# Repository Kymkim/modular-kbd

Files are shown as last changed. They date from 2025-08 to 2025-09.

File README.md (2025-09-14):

# MSKBD - Modularly Simple KeyBoarD

> [!WARNING]  
> This is under development. If you want the latest developments check out the `dev` branch.

A customizable modular keyboard system where each key cluster is its own module, connected through a grid-like commnication. The goal is to create a flexible keyboard that can scale, reconfigure layouts, and support hot-swapping modules.

## Features
- 🧩 **Modular design** — attach modules in any direction
- 🎛️ **Configurable firmware** — master + module code, easily updated
- ⚡ **Hotplug detection** — modules can be discovered dynamically

# Numpad Module

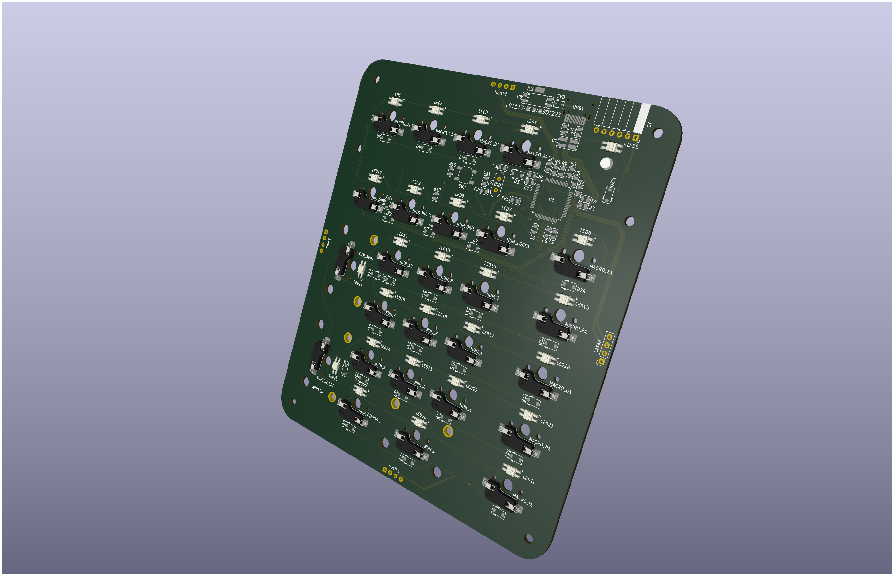
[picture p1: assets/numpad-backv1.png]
Numpad Rear


## Repo Structure
```
├─firmware/ - Embedded code for the core system
├─hardware/ - Schematics and PCB layouts
├─software/ - Host tools (keymap editor, etc.) (not yet implemented - soon hopefully!)
├─docs/ - Design notes, communication protocol, build guides
└─assets/ - Renders, diagrams, and media
```

## Branch Structure
```
main              # Stable, production-ready code (only tested & reviewed changes go here)
│
├─ dev            # Integration branch for features; "staging" area before merging to main
│  ├─ software-xxxxxx     # New features, experiments, improvements, or PCB uploads    
|  ├─ firmware-xxxxxx     # Please indicate in the branch the wether if its software
│  └─ hardware-xxxxxx     # firmware, or hardware
│
├─ hotfix/        # Quick fixes for urgent bugs in main
│   └─ hotfix/usb-detection
│
└─ docs/          # Documentation updates
    └─ docs/protocol-update
```

## Contributors
<a href="https://github.com/Kymkim/modular-kbd/graphs/contributors">
  
</a>

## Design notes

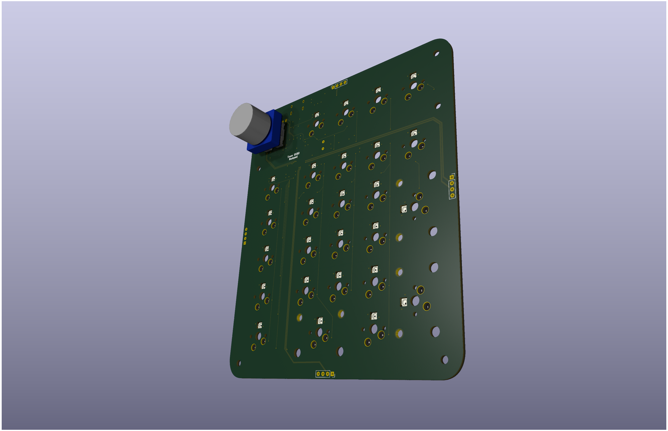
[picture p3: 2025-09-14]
assets/numpad-frontv1.png

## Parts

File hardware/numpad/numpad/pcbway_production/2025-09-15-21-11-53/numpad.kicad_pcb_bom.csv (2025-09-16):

Designator | Quantity | Value | Footprint | Package | MPN | DNP | Mount_Type | Description | Specifications | Manufacturer
C1, C2 | 2 | 20pF | C_0805_2012Metric |  |  |  | smt | SMD 0805 MLCC capacitor, Alternate KiCad Library
C10, C7 | 2 | 1uF | C_0805_2012Metric |  |  |  | smt | SMD 0805 MLCC capacitor, Alternate KiCad Library
C11 | 1 | 0.1uF | C_0805_2012Metric |  |  |  | smt | SMD 0805 MLCC capacitor, Alternate KiCad Library
C3, C4, C5, C6 | 4 | 100nF | C_0805_2012Metric |  |  |  | smt | SMD 0805 MLCC capacitor, Alternate KiCad Library
C8 | 1 | 10uF | C_0805_2012Metric |  |  |  | smt | SMD 0805 MLCC capacitor, Alternate KiCad Library
C9 | 1 | 4.7uF | C_0805_2012Metric |  |  |  | smt | SMD 0805 MLCC capacitor, Alternate KiCad Library
D1 | 1 | PRTR5V0U2X | SOT-143_Handsoldering |  |  |  | smt | SOT-143 TVS Diode Array, 2 protected lines, 5.5V, Alternate KiCAD Library
D10, D11, D12, D13, D14, D15, D16, D17, D18, D19, D20, D21, D22, D23, D24, D25, D26, D27, D28, D29, D3, D4, D5, D6, D7, D8, D9 | 27 | 1N4148W | D_SOD-123 |  |  |  | smt | SOD-123 Diode, Small Signal, Fast Switching, 75V, 150mA, 4ns, Alternate KiCad Library
D2 | 1 | BAT60JFILM | D_SOD-323 |  |  |  | smt | Diode
EAST, NORTH, SOUTH, WEST | 4 | Conn_01x04 | PinSocket_1x04_P2.54mm_Vertical |  | 1-0401FBV0T |  | tht | HEADER 1x4 MALE PINS 0.100” 180deg | HEADER 1x4 MALE PINS 0.100” 180deg | TAD
FB1 | 1 | Ferrite_Bead | Fuse_0805_2012Metric_Pad1.15x1.40mm_BigPads |  |  |  | smt | Ferrite bead, Alternate KiCAD Library
IC1 | 1 | LD1117 | SOT223 |  | LD1117S33CTR |  | tht | 3.3V Voltage Regulator, SOT-223-3, Imax=0.8A, VinMax=15V, Vdrop=1V |  | STMicroelectronics
J1 | 1 | Conn_01x06 | PinSocket_1x06_P2.54mm_Horizontal |  | 1-0601FBV0T |  | tht | HEADER 1x6 MALE PINS 0.100” 180deg | HEADER 1x6 MALE PINS 0.100” 180deg | TAD
LED1, LED10, LED11, LED12, LED13, LED14, LED15, LED16, LED17, LED18, LED19, LED2, LED20, LED21, LED22, LED23, LED24, LED25, LED26, LED27, LED3, LED4, LED5, LED6, LED7, LED8, LED9 | 27 | MX_SK6812MINI-E | LED_MX_6028R |  |  |  | smt | Reverse mount adressable LED (WS2812 protocol)
MACRO_A1, MACRO_B1, MACRO_C1, MACRO_D1, MACRO_E1, MACRO_F1, MACRO_G1, MACRO_H1, MACRO_I1, NUM_0, NUM_1, NUM_10, NUM_2, NUM_3, NUM_4, NUM_5, NUM_6, NUM_7, NUM_8, NUM_ADD1, NUM_DIV1, NUM_ENTER1, NUM_LOCK1, NUM_MULT1, NUM_PERIOD1, NUM_SUB1 | 26 | MX_SW_HS | SW_MX_HS_CPG151101S11_1u |  |  |  | smt | Push button switch, normally open, two pins, 45° tilted, Kailh CPG151101S11 for Cherry MX style switches
R1, R2 | 2 | 5.1k | R_0805_2012Metric |  |  |  | smt | SMD 0805 Chip Resistor, European Symbol, Alternate KiCad Library
R10 | 1 | DNP | R_0805_2012Metric |  |  | Yes | smt | SMD 0805 Chip Resistor, European Symbol, Alternate KiCad Library
R13 | 1 | DNP | R_0805_2012Metric |  |  | Yes | smt | SMD 0805 Chip Resistor, European Symbol, Alternate KiCad Library
R3, R4, R6, R7, R8, R9 | 6 | 22 | R_0805_2012Metric |  |  |  | smt | SMD 0805 Chip Resistor, European Symbol, Alternate KiCad Library
R5 | 1 | 10k | R_0805_2012Metric |  |  |  | smt | SMD 0805 Chip Resistor, European Symbol, Alternate KiCad Library
S1, S2, S3 | 3 | MX_stab | STAB_MX_P_2u |  |  |  | tht | Cherry MX-style stabilizer
SW2 | 1 | Push_Button | SW_SPST_SKQG_WithStem |  |  |  | smt | Common 6mmx6mm Push Button
U1 | 1 | ~ | LQFP64-10x10mm |  |  |  | smt
USB1 | 1 | HRO-TYPE-C-31-M-12 | HRO-TYPE-C-31-M-12-HandSoldering |  |  |  | smt
Y1 | 1 | 8MHz | Crystal_HC52-U_Vertical |  |  |  | tht | 8Mz Crystal

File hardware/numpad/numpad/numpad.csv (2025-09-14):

2"Reference" | Qty | Value | DNP | Exclude from BOM | Exclude from Board | Footprint | Datasheet
C1,C2 | 2 | 20pF |  |  |  | PCM_Capacitor_SMD_AKL:C_0805_2012Metric | ~
C3,C4,C5,C6 | 4 | 100nF |  |  |  | PCM_Capacitor_SMD_AKL:C_0805_2012Metric | ~
C7,C10 | 2 | 1uF |  |  |  | PCM_Capacitor_SMD_AKL:C_0805_2012Metric | ~
C8 | 1 | 10uF |  |  |  | PCM_Capacitor_SMD_AKL:C_0805_2012Metric | ~
C9 | 1 | 4.7uF |  |  |  | PCM_Capacitor_SMD_AKL:C_0805_2012Metric | ~
C11 | 1 | 0.1uF |  |  |  | PCM_Capacitor_SMD_AKL:C_0805_2012Metric | ~
D1 | 1 | PRTR5V0U2X |  |  |  | PCM_Package_TO_SOT_SMD_AKL:SOT-143_Handsoldering | https://www.tme.eu/Document/4eac14af69261014af6cc93b35742953/PRTR5V0U2X-DTE.pdf
D2 | 1 | BAT60JFILM |  |  |  | PCM_Diode_SMD_AKL:D_SOD-323
D3,D4,D5,D6,D7,D8,D9,D10,D11,D12,D13,D14,D15,D16,D17,D18,D19,D20,D21,D22,D23,D24,D25,D26,D27,D28,D29 | 27 | 1N4148W |  |  |  | PCM_Diode_SMD_AKL:D_SOD-123 | https://datasheet.octopart.com/1N4148W-HE3-18-Vishay-datasheet-17291302.pdf
East1,North1,South1,West1 | 4 | Conn_01x04 |  |  |  | Connector_PinSocket_2.54mm:PinSocket_1x04_P2.54mm_Vertical
FB1 | 1 | Ferrite_Bead |  |  |  | PCM_Fuse_AKL:Fuse_0805_2012Metric_Pad1.15x1.40mm_BigPads | ~
IC1 | 1 | LD1117-3.3V-SOT223 |  |  |  | PCM_4ms_Package_SOT:SOT223 | https://www.mouser.com/datasheet/2/389/cd00000544-1795431.pdf
J1 | 1 | Conn_01x06 |  |  |  | Connector_PinSocket_2.54mm:PinSocket_1x06_P2.54mm_Horizontal
LED1,LED2,LED3,LED4,LED5,LED6,LED7,LED8,LED9,LED10,LED11,LED12,LED13,LED14,LED15,LED16,LED17,LED18,LED19,LED20,LED21,LED22,LED23,LED24,LED25,LED26,LED27 | 27 | MX_SK6812MINI-E |  |  |  | PCM_marbastlib-mx:LED_MX_6028R
MACRO_A1,MACRO_B1,MACRO_C1,MACRO_D1,MACRO_E1,MACRO_F1,MACRO_G1,MACRO_H1,MACRO_I1,NUM_0,NUM_1,NUM_2,NUM_3,NUM_4,NUM_5,NUM_6,NUM_7,NUM_8,NUM_10,NUM_ADD1,NUM_DIV1,NUM_ENTER1,NUM_LOCK1,NUM_MULT1,NUM_PERIOD1,NUM_SUB1 | 26 | MX_SW_HS |  |  |  | PCM_marbastlib-mx:SW_MX_HS_CPG151101S11_1u | ~
R1,R2 | 2 | 5.1k |  |  |  | PCM_Resistor_SMD_AKL:R_0805_2012Metric | ~
R3,R4,R6,R7,R8,R9 | 6 | 22 |  |  |  | PCM_Resistor_SMD_AKL:R_0805_2012Metric | ~
R5 | 1 | 10k |  |  |  | PCM_Resistor_SMD_AKL:R_0805_2012Metric | ~
R10,R13 | 2 | DNP |  |  |  | PCM_Resistor_SMD_AKL:R_0805_2012Metric | ~
S1,S2,S3 | 3 | MX_stab |  |  |  | PCM_marbastlib-mx:STAB_MX_P_2u
SW1 | 1 | ROT_SKYLOONG_HS |  | Excluded from BOM |  | PCM_marbastlib-various:ROT_SKYLOONG_HS-Switch | https://skyloong.vip/products/abs-hot-swappable-knobs-madule
SW2 | 1 | Push_Button |  |  |  | PCM_marbastlib-various:SW_SPST_SKQG_WithStem
U1 | 1 | ~ |  |  |  | footprints:LQFP64-10x10mm
USB1 | 1 | HRO-TYPE-C-31-M-12 |  |  |  | Type-C.pretty-master:HRO-TYPE-C-31-M-12-HandSoldering
Y1 | 1 | 8MHz |  |  |  | PCM_Crystal_AKL:Crystal_HC52-U_Vertical

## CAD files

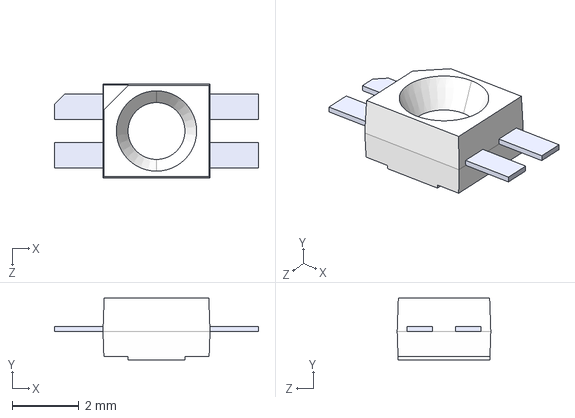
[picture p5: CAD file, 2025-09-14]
hardware/symbols/T36K3BGR-05D000121U1930/T36K3BGR-05D000121U1930.step
6.10 x 1.85 x 2.80 mm

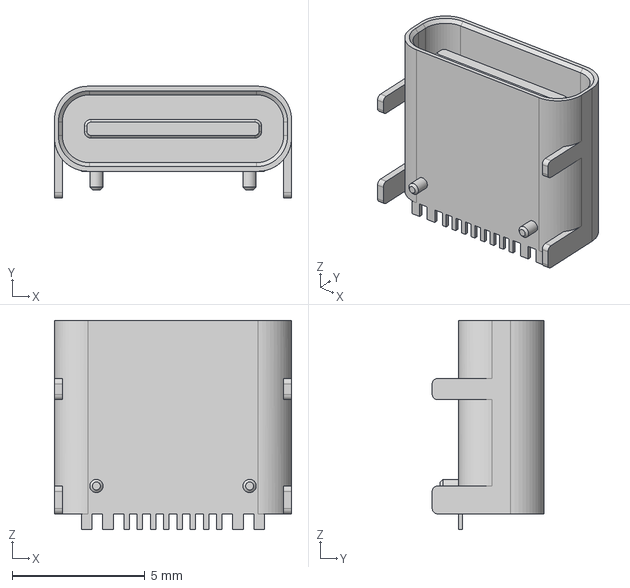
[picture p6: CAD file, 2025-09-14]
hardware/Type-C.pretty-master/HRO TYPE-C-31-M-12.step
8.94 x 4.21 x 7.90 mm

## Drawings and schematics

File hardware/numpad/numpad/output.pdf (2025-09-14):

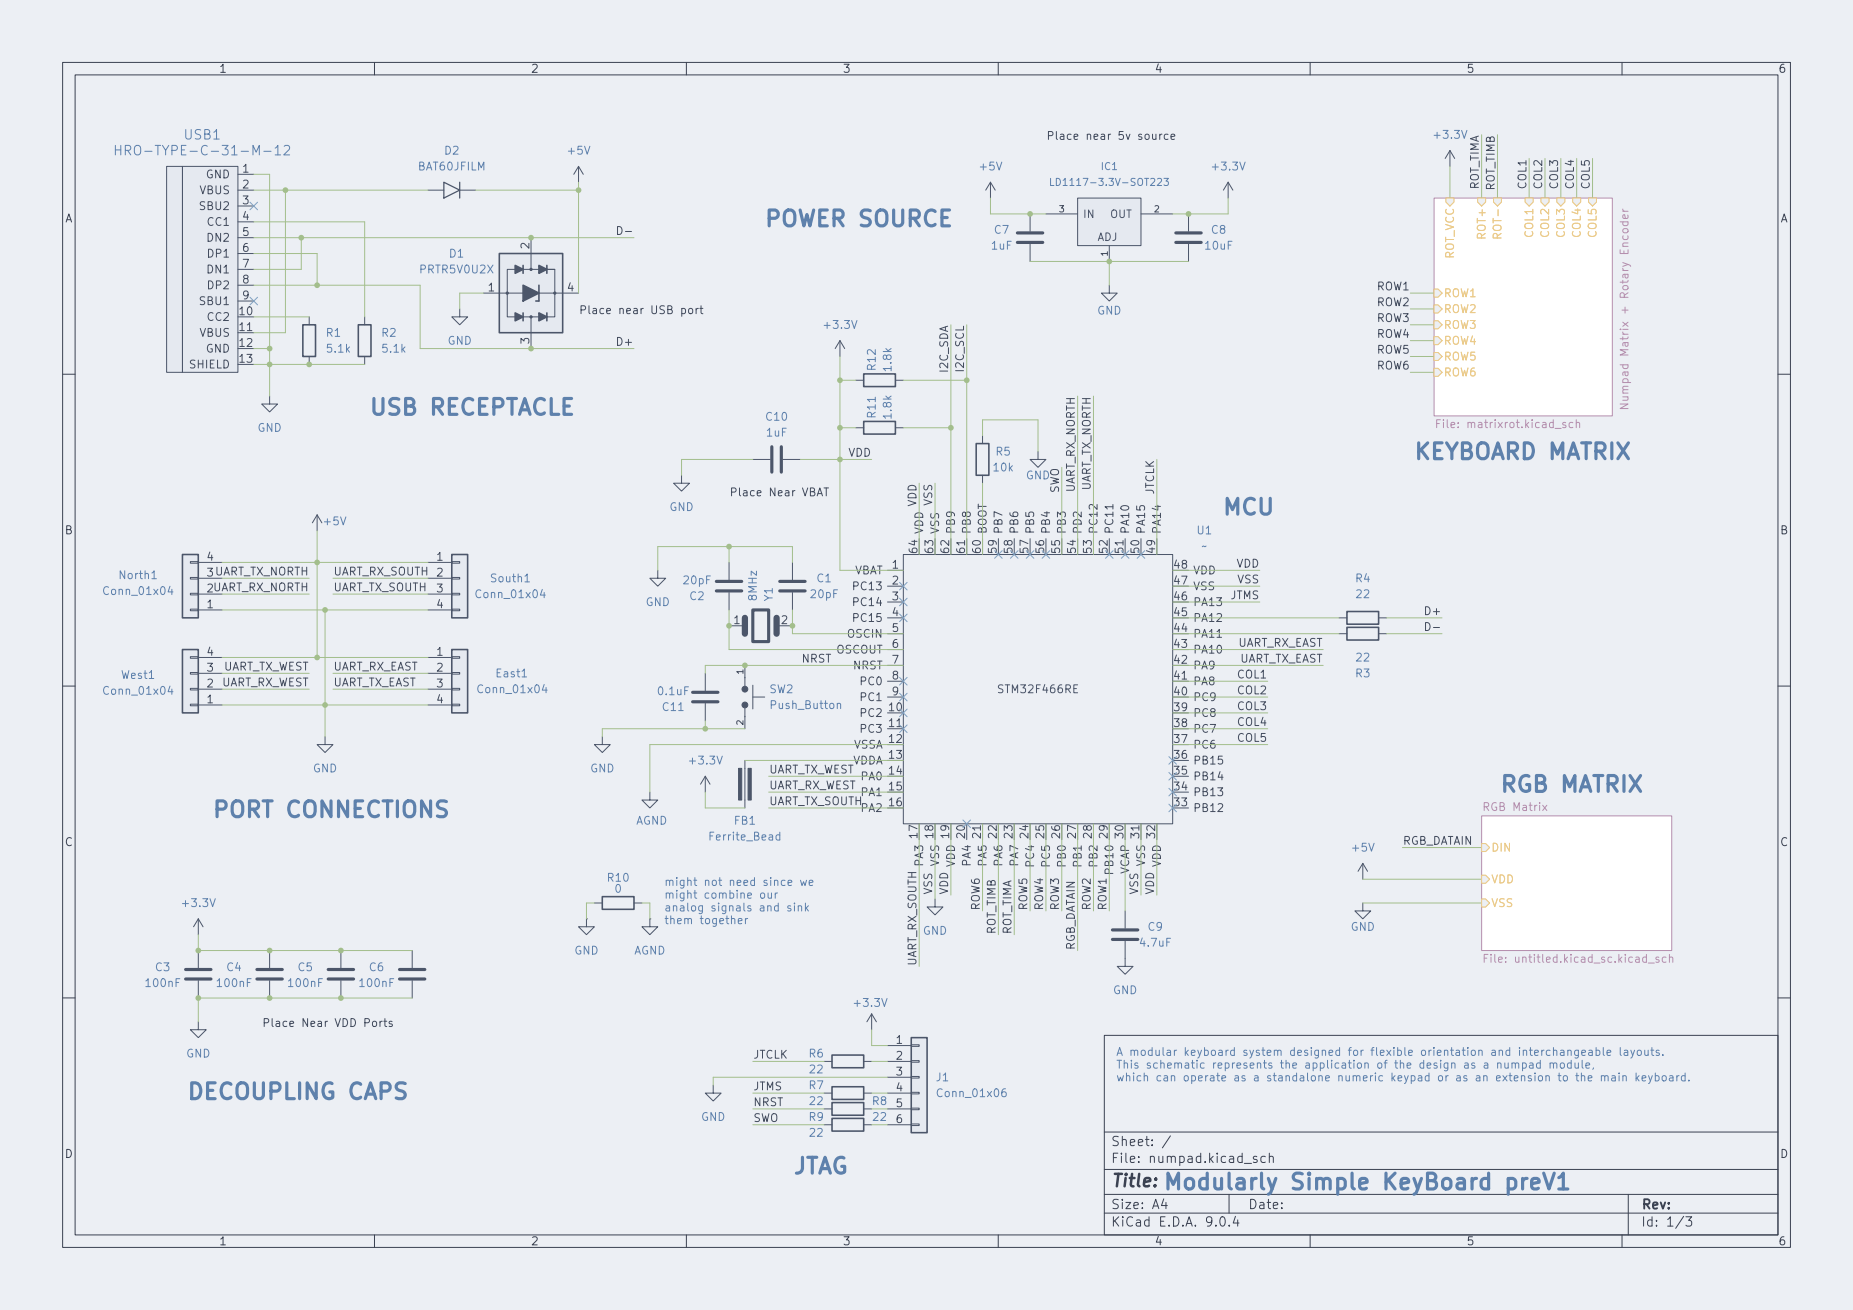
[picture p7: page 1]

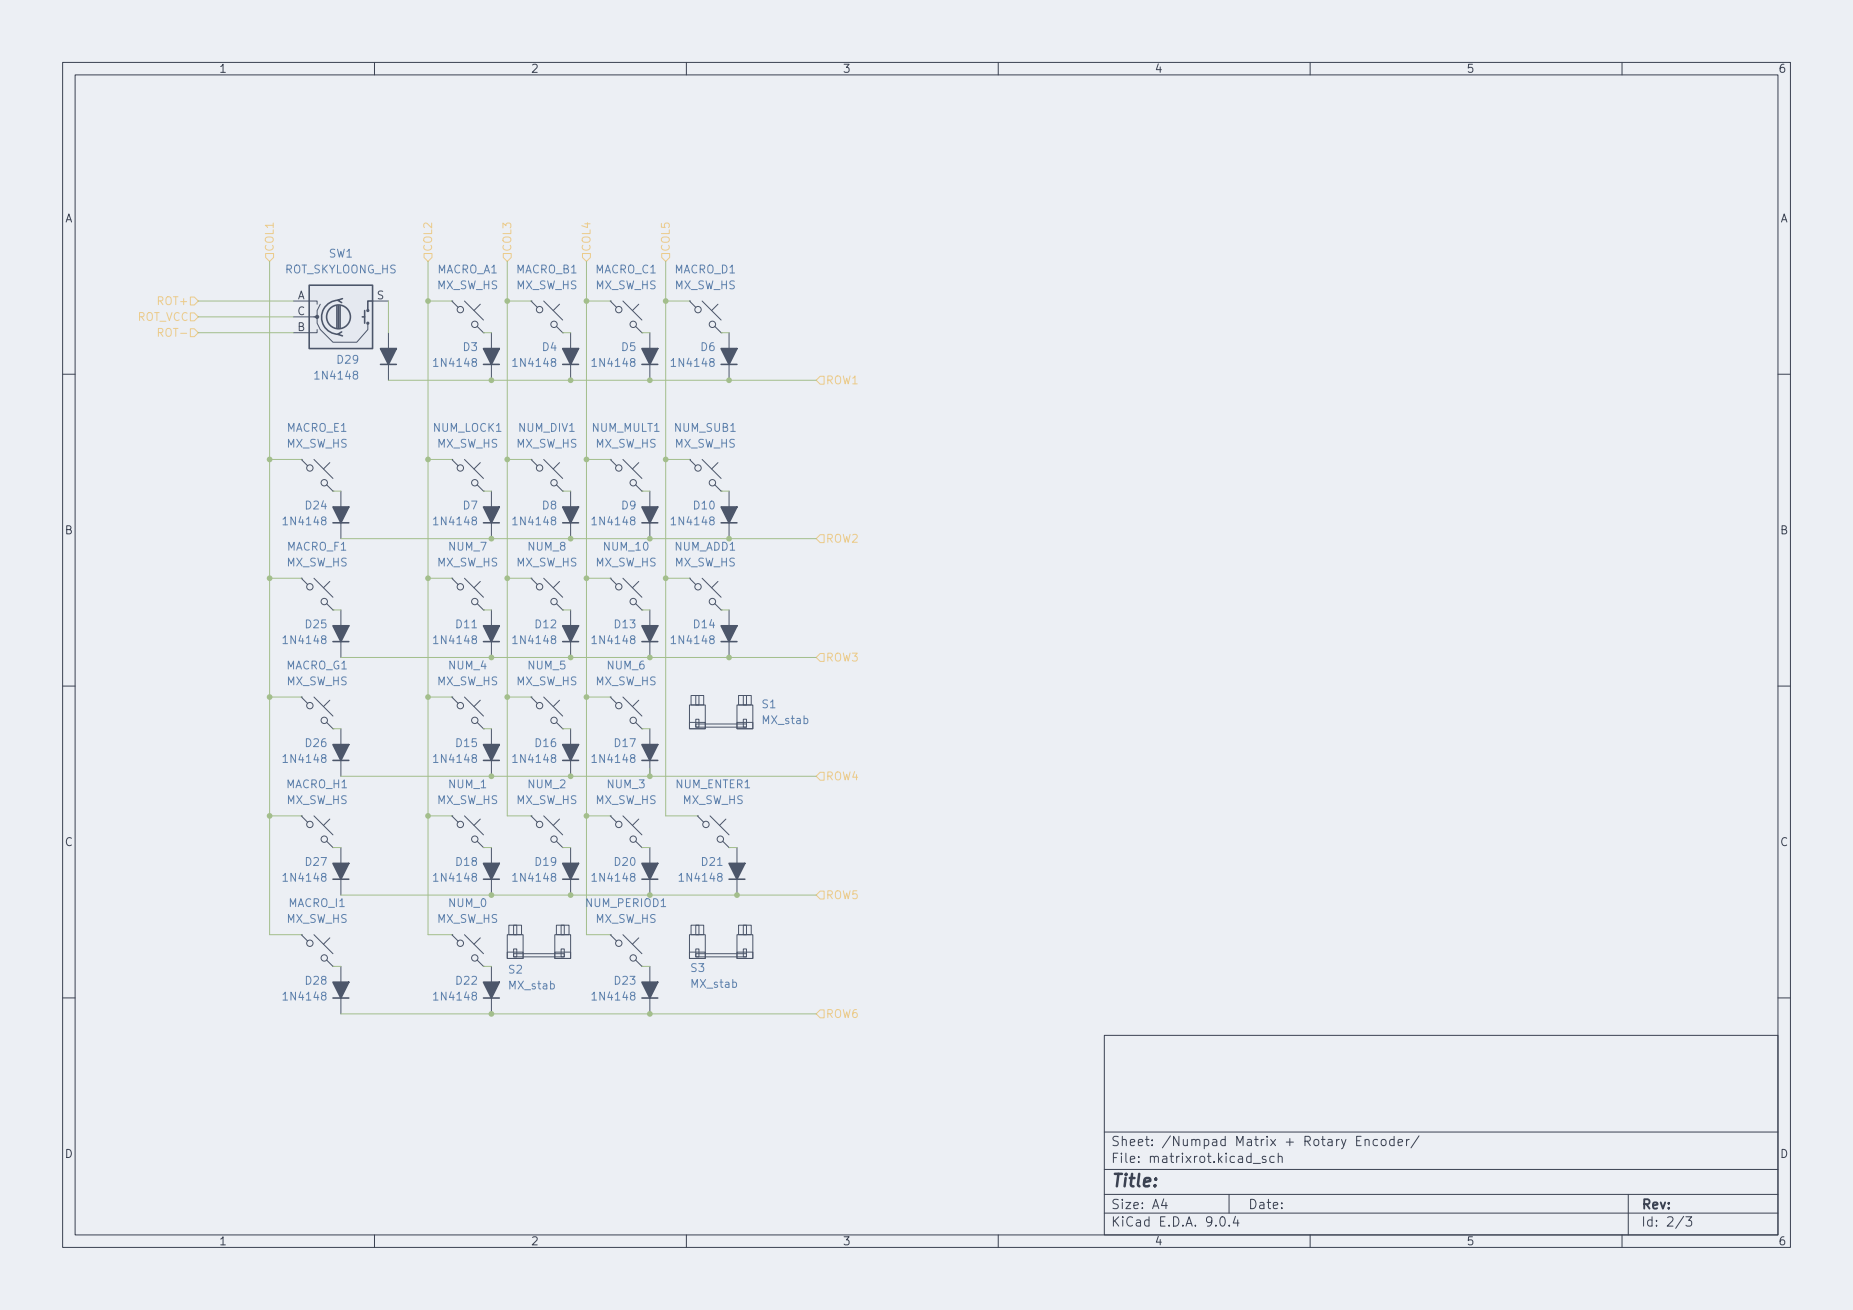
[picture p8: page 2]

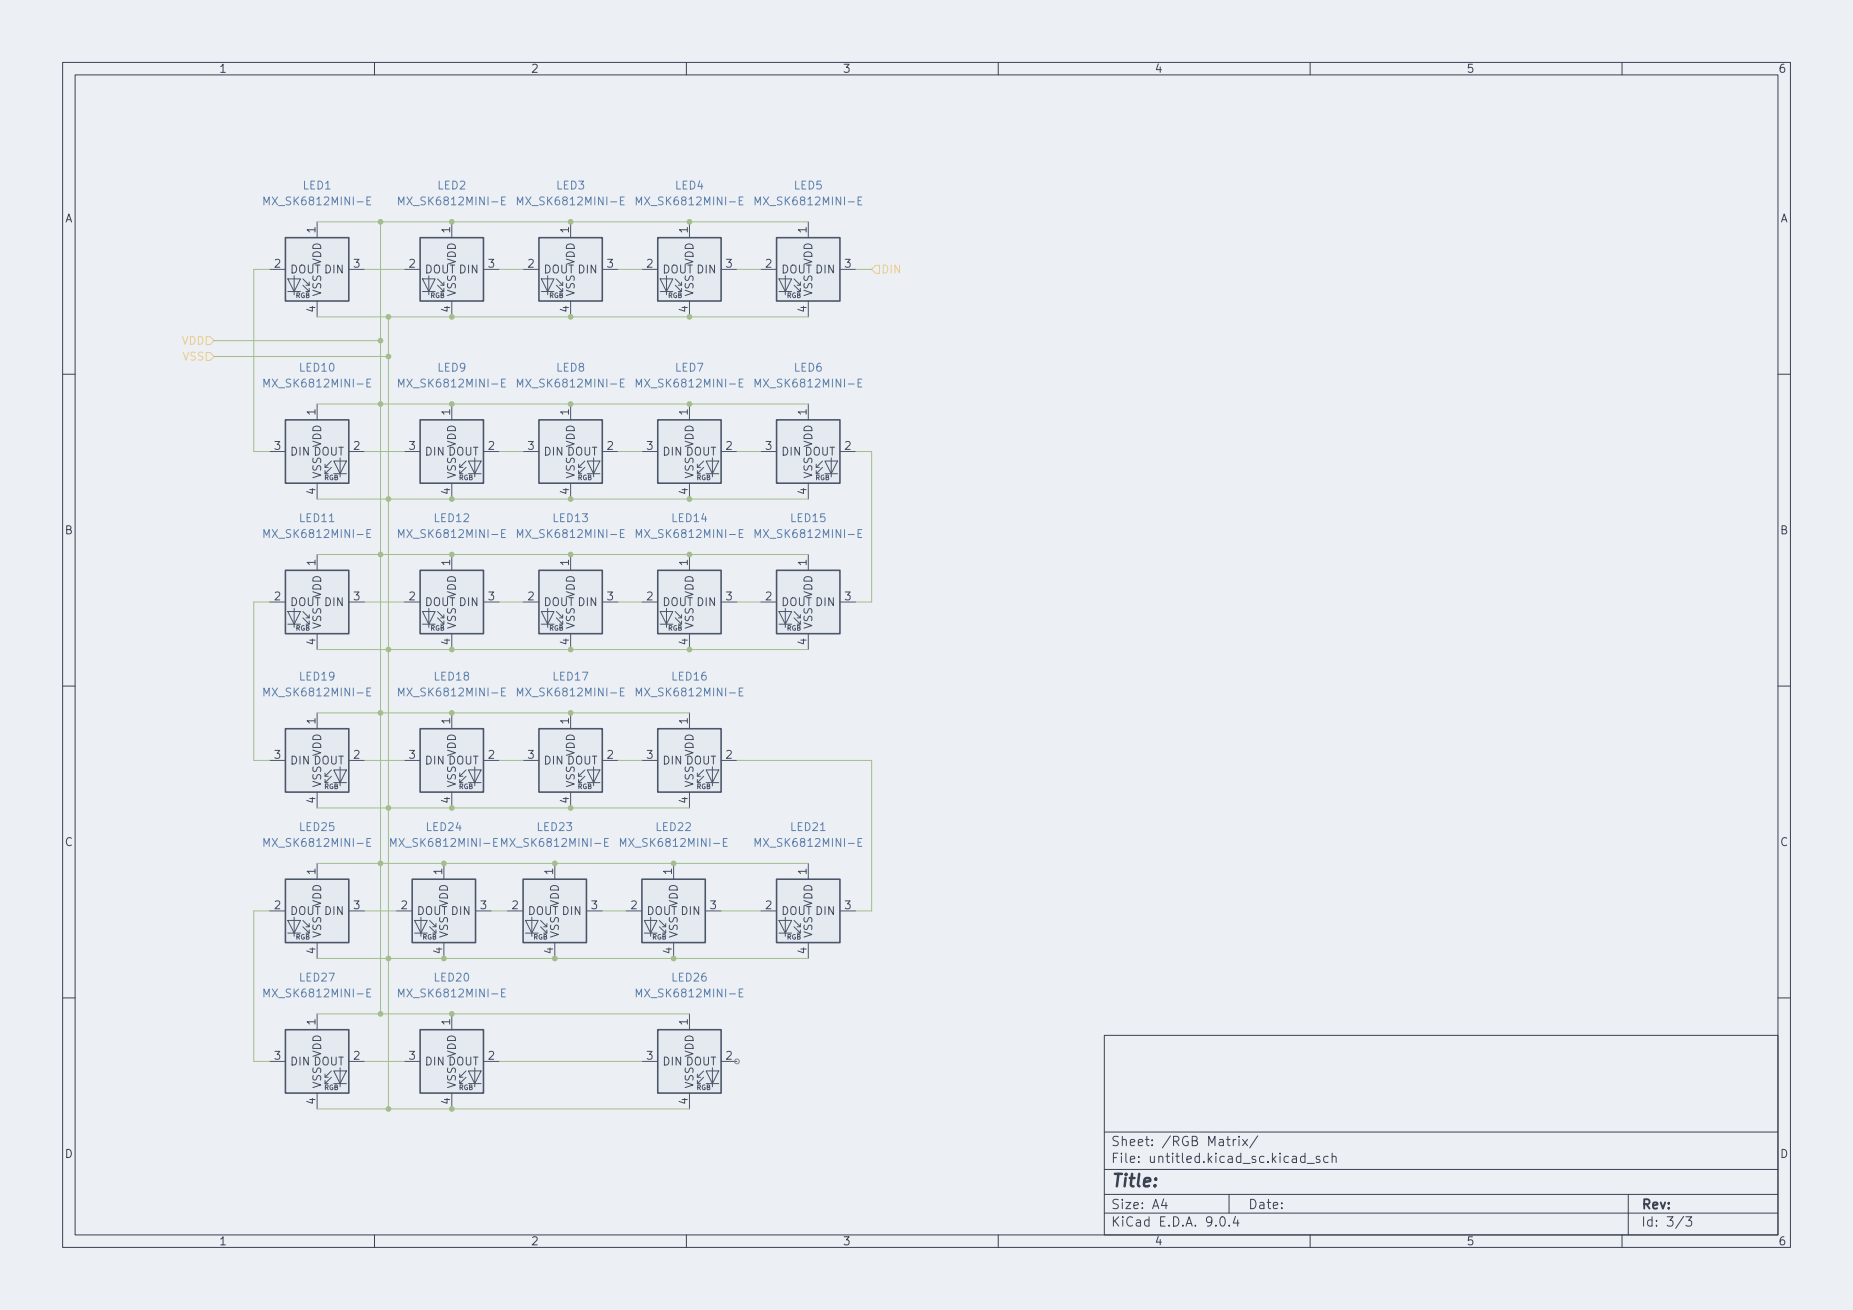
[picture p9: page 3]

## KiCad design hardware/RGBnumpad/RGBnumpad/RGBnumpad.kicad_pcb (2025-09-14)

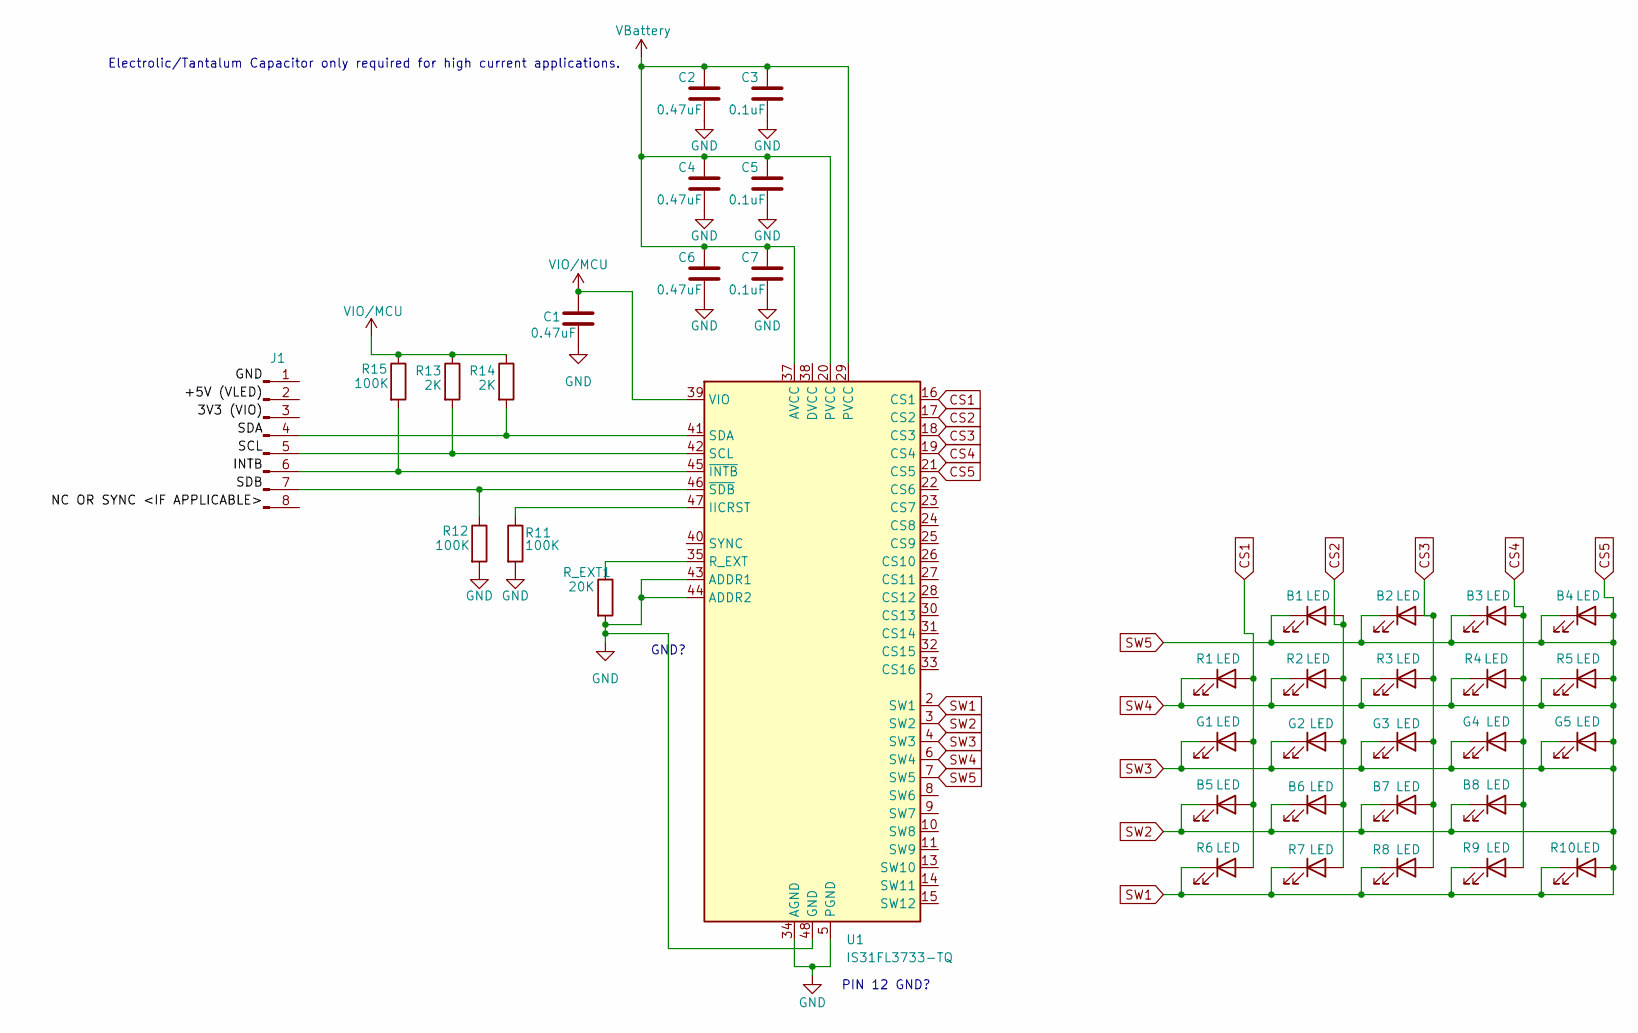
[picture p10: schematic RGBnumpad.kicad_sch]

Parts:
B1, B2, B3, B4, B5, B6, B7, B8: LED; LED_0805_2012Metric_Pad1.15x1.40mm_HandSolder
C1, C2, C4, C6: 0.47uF; C_0805_2012Metric_Pad1.18x1.45mm_HandSolder
C3, C5, C7: 0.1uF; C_0805_2012Metric_Pad1.18x1.45mm_HandSolder
G1, G2, G3, G4, G5: LED; LED_0805_2012Metric_Pad1.15x1.40mm_HandSolder
J1: (no value)
R1, R2, R3, R4, R5, R6, R7, R8, R9, R10: LED; LED_0805_2012Metric_Pad1.15x1.40mm_HandSolder
R11, R12, R15: 100K; R_0805_2012Metric_Pad1.20x1.40mm_HandSolder
R13, R14: 2K; R_0805_2012Metric_Pad1.20x1.40mm_HandSolder
R_EXT1: 20K; R_0805_2012Metric_Pad1.20x1.40mm_HandSolder
U1: IS31FL3733-TQ; TQFP-48-1EP_7x7mm_P0.5mm_EP5x5mm

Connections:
CS1: B5.2 (A), G1.2 (A), R1.2 (A), R6.2 (A), U1.16 (CS1)
CS2: B1.2 (A), B6.2 (A), G2.2 (A), R2.2 (A), R7.2 (A), U1.17 (CS2)
CS3: B2.2 (A), B7.2 (A), G3.2 (A), R3.2 (A), R8.2 (A), U1.18 (CS3)
CS4: B3.2 (A), B8.2 (A), G4.2 (A), R4.2 (A), R9.2 (A), U1.19 (CS4)
CS5: B1.1 (K), B2.1 (K), B3.1 (K), B4.1 (K), B4.2 (A), B5.1 (K), B6.1 (K), B7.1 (K), B8.1 (K), G1.1 (K), G2.1 (K), G3.1 (K), G4.1 (K), G5.1 (K), G5.2 (A), R1.1 (K), R2.1 (K), R3.1 (K), R4.1 (K), R5.1 (K), R5.2 (A), R6.1 (K), R7.1 (K), R8.1 (K), R9.1 (K), R10.1 (K), R10.2 (A), U1.2 (SW1), U1.3 (SW2), U1.4 (SW3), U1.6 (SW4), U1.7 (SW5), U1.21 (CS5)
GND: C1.2, C2.2, C3.2, C4.2, C5.2, C6.2, C7.2, R11.2, R12.2, R_EXT1.2, U1.5 (PGND), U1.12 (PGND), U1.34 (AGND), U1.43 (ADDR1), U1.44 (ADDR2), U1.48 (GND), U1.49 (GND)
unnamed: J1.4, R14.2, U1.41 (SDA)
unnamed: J1.5, R13.2, U1.42 (SCL)
unnamed: J1.6, R15.2, U1.45 (~INTB)
unnamed: J1.7, R12.1, U1.46 (~SDB)
unnamed: R11.1, U1.47 (IICRST)
unnamed: R_EXT1.1, U1.35 (R_EXT)
VBattery: C2.1, C3.1, C4.1, C5.1, C6.1, C7.1, U1.20 (PVCC), U1.29 (PVCC), U1.37 (AVCC)
VIO/MCU: C1.1, R13.1, R14.1, R15.1, U1.39 (VIO)

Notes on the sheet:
PIN 12 GND?
Electrolic/Tantalum Capacitor only required for high current applications.
GND?

Board: 2 copper layers, 37 parts (0 on the bottom side), 14 nets, no tracks yet.

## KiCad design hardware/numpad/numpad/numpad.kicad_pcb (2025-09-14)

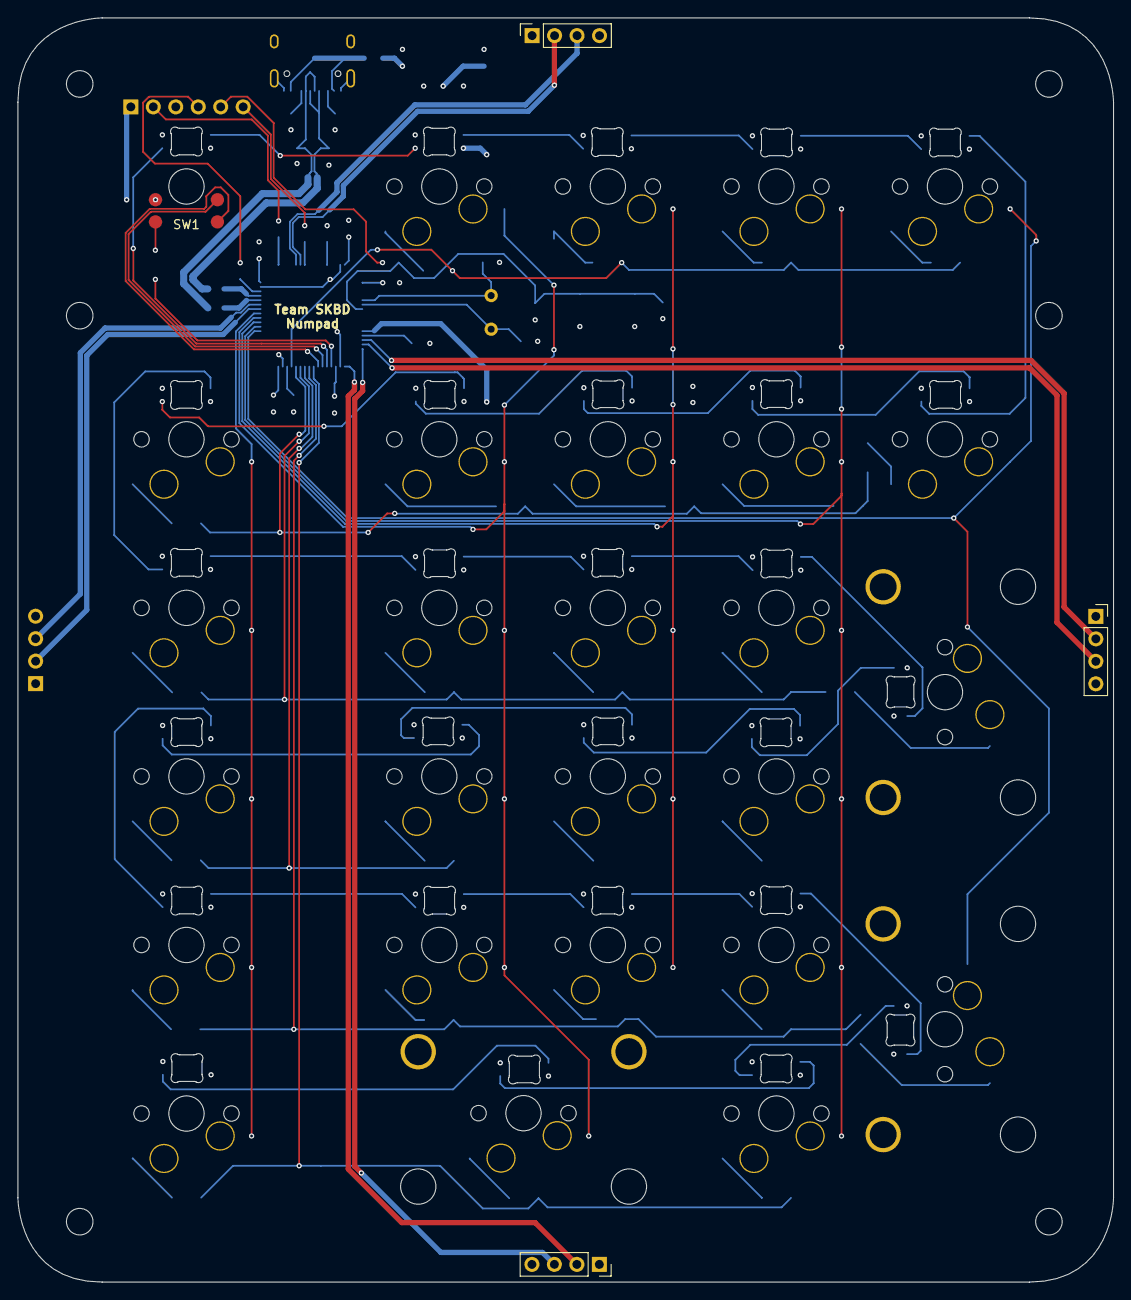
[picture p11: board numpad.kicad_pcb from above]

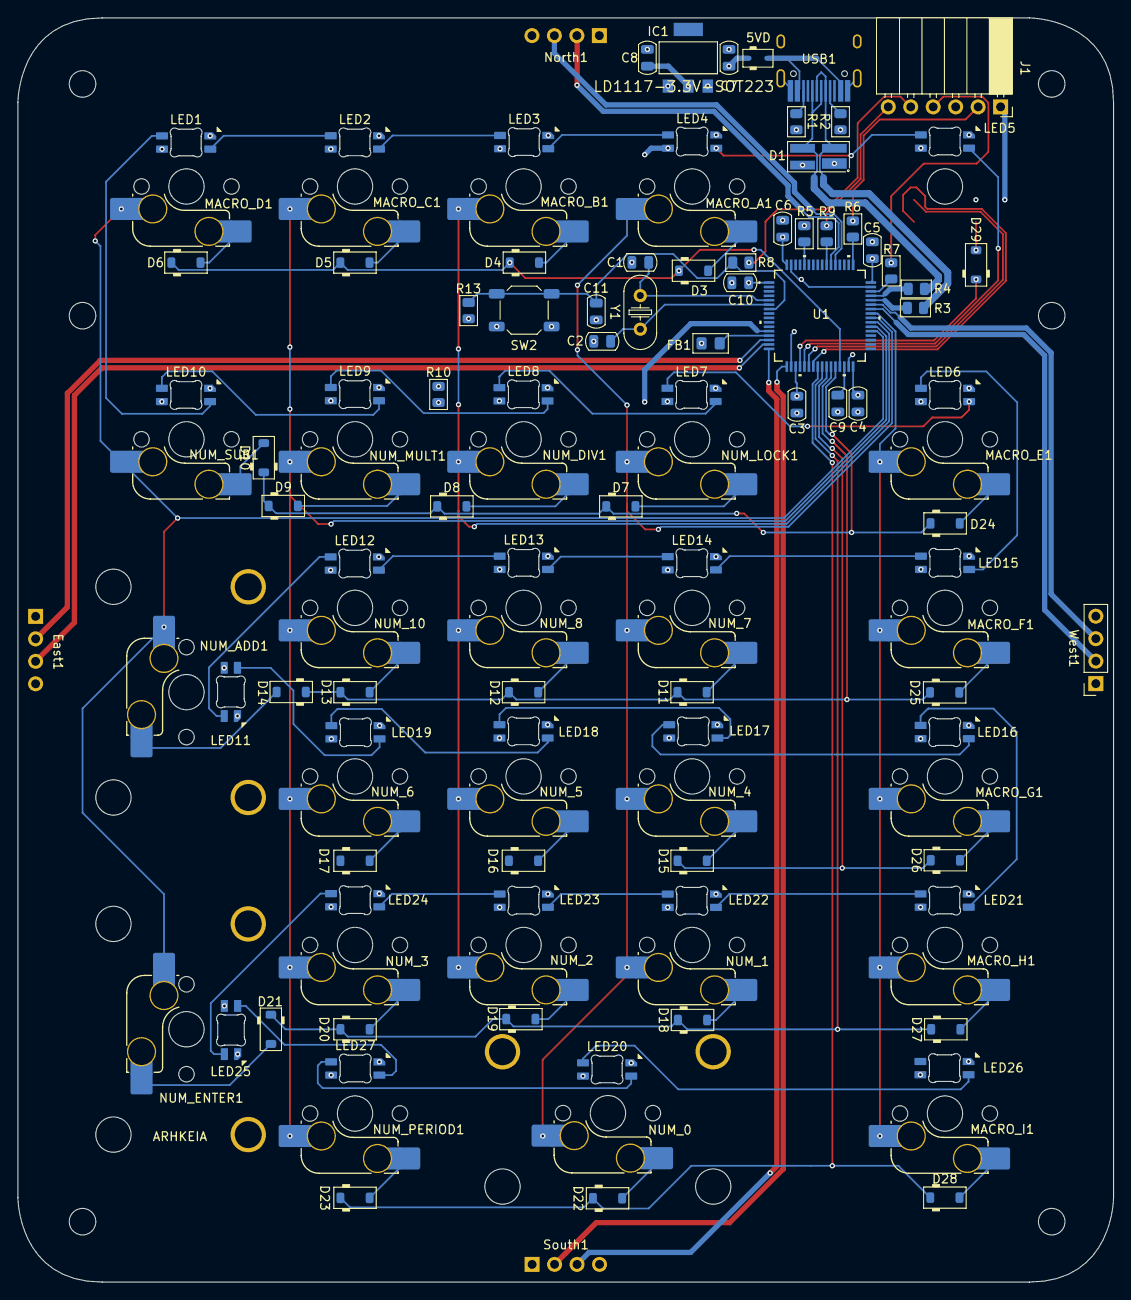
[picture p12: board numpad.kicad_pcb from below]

Board: 4 copper layers, 123.8 x 142.9 mm, 119 parts (112 on the bottom side), 100 nets.

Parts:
C1, C2: 20pF; C_0805_2012Metric
C3, C4, C5, C6: 100nF; C_0805_2012Metric
C7, C10: 1uF; C_0805_2012Metric
C8: 10uF; C_0805_2012Metric
C9: 4.7uF; C_0805_2012Metric
C11: 0.1uF; C_0805_2012Metric
D1: PRTR5V0U2X; SOT-143_Handsoldering
D2: BAT60JFILM; D_SOD-323
D3, D4, D5, D6, D7, D8, D9, D10, D11, D12, D13, D14, D15, D16, D17, D18, D19, D20, D21, D22, D23, D24, D25, D26, D27, D28, D29: 1N4148W; D_SOD-123
East1: Conn_01x04; PinSocket_1x04_P2.54mm_Vertical
FB1: Ferrite_Bead; Fuse_0805_2012Metric_Pad1.15x1.40mm_BigPads
IC1: LD1117-3.3V-SOT223; SOT223
J1: Conn_01x06; PinSocket_1x06_P2.54mm_Horizontal
LED1, LED2, LED3, LED4, LED5, LED6, LED7, LED8, LED9, LED10, LED11, LED12, LED13, LED14, LED15, LED16, LED17, LED18, LED19, LED20, LED21, LED22, LED23, LED24, LED25, LED26, LED27: MX_SK6812MINI-E; LED_MX_6028R
MACRO_A1: MX_SW_HS; SW_MX_HS_CPG151101S11_1u
MACRO_B1: MX_SW_HS; SW_MX_HS_CPG151101S11_1u
MACRO_C1: MX_SW_HS; SW_MX_HS_CPG151101S11_1u
MACRO_D1: MX_SW_HS; SW_MX_HS_CPG151101S11_1u
MACRO_E1: MX_SW_HS; SW_MX_HS_CPG151101S11_1u
MACRO_F1: MX_SW_HS; SW_MX_HS_CPG151101S11_1u
MACRO_G1: MX_SW_HS; SW_MX_HS_CPG151101S11_1u
MACRO_H1: MX_SW_HS; SW_MX_HS_CPG151101S11_1u
MACRO_I1: MX_SW_HS; SW_MX_HS_CPG151101S11_1u
NUM_0, NUM_1, NUM_2, NUM_3, NUM_4, NUM_5, NUM_6, NUM_7, NUM_8, NUM_10: MX_SW_HS; SW_MX_HS_CPG151101S11_1u
NUM_ADD1: MX_SW_HS; SW_MX_HS_CPG151101S11_1u
NUM_DIV1: MX_SW_HS; SW_MX_HS_CPG151101S11_1u
NUM_ENTER1: MX_SW_HS; SW_MX_HS_CPG151101S11_1u
NUM_LOCK1: MX_SW_HS; SW_MX_HS_CPG151101S11_1u
NUM_MULT1: MX_SW_HS; SW_MX_HS_CPG151101S11_1u
NUM_PERIOD1: MX_SW_HS; SW_MX_HS_CPG151101S11_1u
NUM_SUB1: MX_SW_HS; SW_MX_HS_CPG151101S11_1u
North1: Conn_01x04; PinSocket_1x04_P2.54mm_Vertical
R1, R2: 5.1k; R_0805_2012Metric
R3, R4, R6, R7, R8, R9: 22; R_0805_2012Metric
R5: 10k; R_0805_2012Metric
R10, R13: DNP; R_0805_2012Metric
S1, S2, S3: MX_stab; STAB_MX_P_2u
SW1: ROT_SKYLOONG_HS; ROT_SKYLOONG_HS-Switch
SW2: Push_Button; SW_SPST_SKQG_WithStem
South1: Conn_01x04; PinSocket_1x04_P2.54mm_Vertical
U1: LQFP64-10x10mm
USB1: HRO-TYPE-C-31-M-12; HRO-TYPE-C-31-M-12-HandSoldering
West1: Conn_01x04; PinSocket_1x04_P2.54mm_Vertical
Y1: 8MHz; Crystal_HC52-U_Vertical

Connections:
+3.3V: C3.1, C4.1, C5.1, C6.1, C8.2, C10.1, FB1.2, IC1.2 (OUT), J1.1, R13.2, SW1.C, U1.1 (VBAT), U1.19 (VDD), U1.32 (VDD), U1.48 (VDD), U1.64 (VDD)
+5V: C7.1, D1.4 (VP), D2.1 (K), East1.1, IC1.3 (IN), LED1.1 (VDD), LED2.1 (VDD), LED3.1 (VDD), LED4.1 (VDD), LED5.1 (VDD), LED6.1 (VDD), LED7.1 (VDD), LED8.1 (VDD), LED9.1 (VDD), LED10.1 (VDD), LED11.1 (VDD), LED12.1 (VDD), LED13.1 (VDD), LED14.1 (VDD), LED15.1 (VDD), LED16.1 (VDD), LED17.1 (VDD), LED18.1 (VDD), LED19.1 (VDD), LED20.1 (VDD), LED21.1 (VDD), LED22.1 (VDD), LED23.1 (VDD), LED24.1 (VDD), LED25.1 (VDD), LED26.1 (VDD), LED27.1 (VDD), North1.4, South1.1, West1.4
/COL1: MACRO_E1.1, MACRO_F1.1, MACRO_G1.1, MACRO_H1.1, MACRO_I1.1, U1.41 (PA8)
/COL2: MACRO_A1.1, NUM_0.1, NUM_1.1, NUM_4.1, NUM_7.1, NUM_LOCK1.1, U1.40 (PC9)
/COL3: MACRO_B1.1, NUM_2.1, NUM_5.1, NUM_8.1, NUM_DIV1.1, U1.39 (PC8)
/COL4: MACRO_C1.1, NUM_3.1, NUM_6.1, NUM_10.1, NUM_MULT1.1, NUM_PERIOD1.1, U1.38 (PC7)
/COL5: MACRO_D1.1, NUM_ADD1.1, NUM_ENTER1.1, NUM_SUB1.1, U1.37 (PC6)
/D+: D1.3 (L2), R4.1, USB1.6 (DP1), USB1.8 (DP2)
/D-: D1.2 (L1), R3.2, USB1.5 (DN2), USB1.7 (DN1)
/JTCLK: R6.2, U1.49 (PA14)
/JTMS: R7.2, U1.46 (PA13)
/NRST: C11.2, R8.1, R13.1, SW2.1, U1.7 (NRST)
/RGB_DATAIN: LED5.3 (DIN), U1.21 (PA5)
/ROT_SW: D29.1 (K), U1.20 (PA4)
/ROT_TIMA: SW1.A, U1.23 (PA7)
/ROT_TIMB: SW1.B, U1.22 (PA6)
/ROW1: D3.1 (K), D4.1 (K), D5.1 (K), D6.1 (K), U1.29 (PB10)
/ROW2: D7.1 (K), D8.1 (K), D9.1 (K), D10.1 (K), D24.1 (K), U1.28 (PB2)
/ROW3: D11.1 (K), D12.1 (K), D13.1 (K), D14.1 (K), D25.1 (K), U1.27 (PB1)
/ROW4: D15.1 (K), D16.1 (K), D17.1 (K), D26.1 (K), U1.26 (PB0)
/ROW5: D18.1 (K), D19.1 (K), D20.1 (K), D21.1 (K), D27.1 (K), U1.25 (PC5)
/ROW6: D22.1 (K), D23.1 (K), D28.1 (K), U1.24 (PC4)
/SWO: R9.2, U1.55 (PB3)
/UART_RX_EAST: East1.2, U1.14 (PA0)
/UART_RX_NORTH: North1.2, U1.54 (PD2)
/UART_RX_SOUTH: South1.2, U1.17 (PA3)
/UART_RX_WEST: U1.42 (PA9), West1.2
/UART_TX_EAST: East1.3, U1.15 (PA1)
/UART_TX_NORTH: North1.3, U1.53 (PC12)
/UART_TX_SOUTH: South1.3, U1.16 (PA2)
/UART_TX_WEST: U1.43 (PA10), West1.3
AGND: R10.1, U1.12 (VSSA)
GND: C1.2, C2.2, C3.2, C4.2, C5.2, C6.2, C7.2, C8.1, C9.1, C10.2, C11.1, D1.1 (VN), East1.4, IC1.1 (ADJ), J1.3, LED1.4 (VSS), LED2.4 (VSS), LED3.4 (VSS), LED4.4 (VSS), LED5.4 (VSS), LED6.4 (VSS), LED7.4 (VSS), LED8.4 (VSS), LED9.4 (VSS), LED10.4 (VSS), LED11.4 (VSS), LED12.4 (VSS), LED13.4 (VSS), LED14.4 (VSS), LED15.4 (VSS), LED16.4 (VSS), LED17.4 (VSS), LED18.4 (VSS), LED19.4 (VSS), LED20.4 (VSS), LED21.4 (VSS), LED22.4 (VSS), LED23.4 (VSS), LED24.4 (VSS), LED25.4 (VSS), LED26.4 (VSS), LED27.4 (VSS), North1.1, R1.2, R2.2, R5.1, R10.2, SW2.2, South1.4, U1.18 (VSS), U1.31 (VSS), U1.47 (VSS), U1.63 (VSS), USB1.1 (GND), USB1.12 (GND), USB1.13 (SHIELD), West1.1
unnamed: D2.2 (A), USB1.2 (VBUS), USB1.11 (VBUS)
unnamed: D3.2 (A), MACRO_A1.2
unnamed: D4.2 (A), MACRO_B1.2
unnamed: D5.2 (A), MACRO_C1.2
unnamed: D6.2 (A), MACRO_D1.2
unnamed: D7.2 (A), NUM_LOCK1.2
unnamed: D8.2 (A), NUM_DIV1.2
unnamed: D9.2 (A), NUM_MULT1.2
unnamed: D10.2 (A), NUM_SUB1.2
unnamed: D11.2 (A), NUM_7.2
unnamed: D12.2 (A), NUM_8.2
unnamed: D13.2 (A), NUM_10.2
unnamed: D14.2 (A), NUM_ADD1.2
unnamed: D15.2 (A), NUM_4.2
unnamed: D16.2 (A), NUM_5.2
unnamed: D17.2 (A), NUM_6.2
unnamed: D18.2 (A), NUM_1.2
unnamed: D19.2 (A), NUM_2.2
unnamed: D20.2 (A), NUM_3.2
unnamed: D21.2 (A), NUM_ENTER1.2
unnamed: D22.2 (A), NUM_0.2
unnamed: D23.2 (A), NUM_PERIOD1.2
unnamed: D24.2 (A), MACRO_E1.2
unnamed: D25.2 (A), MACRO_F1.2
unnamed: D26.2 (A), MACRO_G1.2
unnamed: D27.2 (A), MACRO_H1.2
unnamed: D28.2 (A), MACRO_I1.2
unnamed: D29.2 (A), SW1.S
unnamed: J1.2, R6.1
unnamed: J1.4, R7.1
unnamed: J1.5, R8.2
unnamed: J1.6, R9.1
unnamed: LED1.3 (DIN), LED2.2 (DOUT)
unnamed: LED1.2 (DOUT), LED10.3 (DIN)
unnamed: LED2.3 (DIN), LED3.2 (DOUT)
unnamed: LED3.3 (DIN), LED4.2 (DOUT)
unnamed: LED4.3 (DIN), LED5.2 (DOUT)
unnamed: LED6.3 (DIN), LED7.2 (DOUT)
unnamed: LED7.3 (DIN), LED8.2 (DOUT)
unnamed: LED8.3 (DIN), LED9.2 (DOUT)
unnamed: LED9.3 (DIN), LED10.2 (DOUT)
unnamed: LED11.3 (DIN), LED12.2 (DOUT)
unnamed: LED11.2 (DOUT), LED19.3 (DIN)
unnamed: LED12.3 (DIN), LED13.2 (DOUT)
unnamed: LED13.3 (DIN), LED14.2 (DOUT)
unnamed: LED14.3 (DIN), LED15.2 (DOUT)
unnamed: LED6.2 (DOUT), LED15.3 (DIN)
unnamed: LED16.3 (DIN), LED17.2 (DOUT)
unnamed: LED16.2 (DOUT), LED21.3 (DIN)
unnamed: LED17.3 (DIN), LED18.2 (DOUT)
unnamed: LED18.3 (DIN), LED19.2 (DOUT)
unnamed: LED20.3 (DIN), LED27.2 (DOUT)
unnamed: LED20.2 (DOUT), LED26.3 (DIN)
unnamed: LED21.2 (DOUT), LED22.3 (DIN)
unnamed: LED22.2 (DOUT), LED23.3 (DIN)
unnamed: LED23.2 (DOUT), LED24.3 (DIN)
unnamed: LED24.2 (DOUT), LED25.3 (DIN)
unnamed: LED25.2 (DOUT), LED27.3 (DIN)
unnamed: R5.2, U1.60 (BOOT)
unnamed: C1.1, U1.5 (OSCIN), Y1.2
unnamed: C2.1, U1.6 (OSCOUT), Y1.1
unnamed: R3.1, U1.44 (PA11)
unnamed: R4.2, U1.45 (PA12)
unnamed: C9.2, U1.30 (VCAP)
unnamed: FB1.1, U1.13 (VDDA)
unnamed: R2.1, USB1.4 (CC1)
unnamed: R1.1, USB1.10 (CC2)

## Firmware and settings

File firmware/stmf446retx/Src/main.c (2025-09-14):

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
/* Includes ------------------------------------------------------------------*/
#include "main.h"
#include "can.h"
#include "usb_device.h"
#include "mainboard_usb.h"
#include "gpio.h"

/* USER CODE BEGIN PTD */
typedef struct{
  uint8_t MODIFIER;
  uint8_t RESERVED;
  uint8_t KEYPRESS[12];
} HIDReportNKRO;

typedef struct{
  uint8_t MODIFIER;
  uint8_t RESERVED;
  uint8_t KEYPRESS[6]; // for 6 Key Rollover, changed index to 6.
} HIDReport6KRO;

typedef struct{
  GPIO_TypeDef* PORT;
  uint16_t PIN;
} KbdPins;

extern USBD_HandleTypeDef hUsbDeviceFS;
/* USER CODE END PTD */

/* USER CODE BEGIN PD */
#define ROWS 2
#define COLS 2
/* USER CODE END PD */


/* USER CODE BEGIN PV */
uint8_t matrix[ROWS][COLS] = {
  {KEY_M, KEY_K},
  {KEY_I, KEY_U}
};
KbdPins row_pins[ROWS] = {
  {GPIOC, GPIO_PIN_6},
  {GPIOB, GPIO_PIN_15}
};
KbdPins col_pins[COLS] = {
  {GPIOB, GPIO_PIN_14},
  {GPIOB, GPIO_PIN_13}
};
HIDReportNKRO REPORT = {0,0,0,0,0,0,0,0};
CAN_RxHeaderTypeDef RxHeader;
uint8_t RxData[8];
/* USER CODE END PV */

void SystemClock_Config(void);
/* USER CODE BEGIN PFP */
void addHIDReport(uint8_t usageID, uint8_t isPressed);
/* USER CODE END PFP */

/**
  * @brief  The application entry point.
  * @retval int
  */
int main(void)
{

  /* MCU Configuration--------------------------------------------------------*/

  /* Reset of all peripherals, Initializes the Flash interface and the Systick. */
  HAL_Init();

  /* Configure the system clock */
  SystemClock_Config();

  /* Initialize all configured peripherals */
  MX_GPIO_Init();
  MX_CAN1_Init();
  MX_USB_DEVICE_Init();
  /* USER CODE BEGIN 2 */
  HAL_CAN_Start(&hcan1);
  HAL_CAN_ActivateNotification(&hcan1, CAN_IT_RX_FIFO0_MSG_PENDING);
  HAL_Delay(50);
  /* USER CODE END 2 */
  
  /* Infinite loop */
  /* USER CODE BEGIN WHILE */
  while (1)
  {
    //Keycode Scan
    // Clear keypresses at the start of each scan for 6 key rollover
    /* USER CODE END WHILE */
    // for(int col = 0; col < COLS; col++){
    //   HAL_GPIO_WritePin(col_pins[col].PORT, col_pins[col].PIN, GPIO_PIN_SET);
    //   HAL_Delay(1);
    //   for(int row = 0; row < ROWS; row++){
    //     if(HAL_GPIO_ReadPin(row_pins[row].PORT, row_pins[row].PIN)){
    //       addHIDReport(matrix[row][col], 1);
    //     }
    //   }
    //   HAL_GPIO_WritePin(col_pins[col].PORT, col_pins[col].PIN, GPIO_PIN_RESET);
    // } for(int col = 0; col < COLS; col++){
    //   HAL_GPIO_WritePin(col_pins[col].PORT, col_pins[col].PIN, GPIO_PIN_SET);
    //   HAL_Delay(1);
    //   for(int row = 0; row < ROWS; row++){
    //     if(HAL_GPIO_ReadPin(row_pins[row].PORT, row_pins[row].PIN)){
    //       addHIDReport(matrix[row][col], 1);
    //     }
    //   }
    //   HAL_GPIO_WritePin(col_pins[col].PORT, col_pins[col].PIN, GPIO_PIN_RESET);
    // }
    USBD_HID_SendReport(&hUsbDeviceFS, (uint8_t*)&REPORT, sizeof(REPORT));
    HAL_Delay(20);
    /* USER CODE BEGIN 3 */
  }
  /* USER CODE END 3 */
}

void HAL_CAN_RxFifo0MsgPendingCallback(CAN_HandleTypeDef *hcan)
{
  HAL_CAN_GetRxMessage(hcan, CAN_RX_FIFO0, &RxHeader, RxData);
  addHIDReport(RxData[0], (RxData[1] & 0x01) ? 1 : 0);
}
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
/* USER CODE BEGIN 4 */
//Converts UsageID to NKRO bit field and add it to the report
void addHIDReport(uint8_t usageID, uint8_t isPressed){
  if(usageID < 0x04 || usageID > 0x73) return; //Usage ID is out of bounds
  uint16_t bit_index = usageID - 0x04; //Offset, UsageID starts with 0x04. Gives us the actual value of the bit
  uint8_t byte_index = bit_index/8;    //Calculates which byte in the REPORT array 
  uint8_t bit_offset = bit_index%8;    //Calculates which bits in the REPORT[byte_index] should be set/unset

  if(isPressed){
    REPORT.KEYPRESS[byte_index] |= (1 << bit_offset);
  }else{
    REPORT.KEYPRESS[byte_index] &= ~(1 << bit_offset);
  }
}

// 6 KEY ROLLOVER CODE STRUCTURE
/*
if (usageID < 0x04 || usageID > 0x73) return;

    int i, empty = -1;
    if (isPressed) {
        for (i = 0; i < 6; i++) {
            if (REPORT.KEYPRESS[i] == usageID) return; // Already present
            if (REPORT.KEYPRESS[i] == 0 && empty == -1) empty = i;
        }
        if (empty != -1) {
            REPORT.KEYPRESS[empty] = usageID;
        }
        // If no empty slot, ignore (6KRO: only 6 keys allowed)
    } else {
        // Remove from the array when released
        for (i = 0; i < 6; i++) {
            if (REPORT.KEYPRESS[i] == usageID) {
                REPORT.KEYPRESS[i] = 0;
            }
        }
    }
*/

/* USER CODE END 4 */
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


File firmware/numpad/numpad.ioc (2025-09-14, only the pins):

Mcu.UserName=STM32F446RETx
PA0-WKUP.Signal=UART4_TX
PA1.Signal=UART4_RX
PA10.Signal=USART1_RX
PA11.Signal=USB_OTG_FS_DM
PA12.Signal=USB_OTG_FS_DP
PA13.Signal=SYS_JTMS-SWDIO
PA14.Signal=SYS_JTCK-SWCLK
PA2.Signal=USART2_TX
PA3.Signal=USART2_RX
PA8.GPIO_Label=COL4
PA8.Signal=GPIO_Output
PA9.Signal=USART1_TX
PB0.GPIO_Label=ROW4
PB0.Signal=GPIO_Input
PB1.GPIO_Label=ROW3
PB1.Signal=GPIO_Input
PB10.GPIO_Label=ROW1SR
PB10.Signal=GPIO_Input
PB2.GPIO_Label=ROW2
PB2.Signal=GPIO_Input
PB4.GPIO_Label=WDebug
PB4.Signal=GPIO_Output
PB5.GPIO_Label=SDebug
PB5.Signal=GPIO_Output
PB6.GPIO_Label=EDebug
PB6.Signal=GPIO_Output
PB7.GPIO_Label=NDebug
PB7.Signal=GPIO_Output
PB8.Signal=I2C1_SCL
PB9.Signal=I2C1_SDA
PC12.Signal=UART5_TX
PC4.GPIO_Label=ROW6
PC4.Signal=GPIO_Input
PC5.GPIO_Label=ROW5
PC5.Signal=GPIO_Input
PC7.GPIO_Label=COL1
PC7.Signal=GPIO_Output
PC8.GPIO_Label=COL2
PC8.Signal=GPIO_Output
PC9.GPIO_Label=COL3
PC9.Signal=GPIO_Output
PD2.Signal=UART5_RX
PH0-OSC_IN.Signal=RCC_OSC_IN
PH1-OSC_OUT.Signal=RCC_OSC_OUT

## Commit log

2025-06-06 config for the can bus for module
2025-06-19 Add full STM32CubeIDE SKBD_Matrix project for 2x2 keypad
2025-06-22 not working. should make the led flash if button on pa10 is pressed.
    [main.c]
2025-06-24 Note on STM32 CAN Filter Bank Number
2025-06-25 fix: update CAN filter bank configuration to valid range
2025-06-25 Add CAN communication and GPIO control functionality
    - Created HAL configuration file for STM32F1xx (stm32f1xx_hal_conf.h).
    - Added interrupt handler definitions in stm32f1xx_it.h.
    - Implemented CAN initialization and configuration in can.c.
    - Configured GPIO pins for output and external interrupts in gpio.c.
    - Developed main application logic in main.c for toggling an LED and sending CAN messages.
    - Implemented MSP initialization and de-initialization for CAN in stm32f1xx_hal_msp.c.
    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
2025-06-26 initial main board
2025-07-15 sample 2x2 modul
2025-07-15 prototype mainboard done!
2025-08-18 Licensce and file restructuring. Housekeeping rules
    [4x4macropad.kicad_pcb, 4x4macropad.kicad_sch, clock.kicad_sch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]
2025-08-18 connectors for other modules
    [numpad.kicad_sch, powerreg.kicad_sch]
2025-08-25 USB; Coupling Caps; and XTAL schematic
    [HRO TYPE-C-31-M-12.step]
2025-08-26 numpad, connections, and more
    [matrixrot.kicad_sch, numpad.kicad_sch]
2025-08-27 draft pcb
    [numpad.kicad_sch]
2025-08-28 typo in schematic
    i changed the GNDA to AGND
    [numpad.kicad_sch]
2025-08-28 diode name + agnd --> gnd
    added the bat and added the jump from agnd and gnd that mayyyyy be needed
    [numpad.kicad_sch]
2025-09-01 RGBnumpad
    Added RBGnumpad w/ symbols
    Still need to assign footprints
    [RGBnumpad.kicad_pcb, RGBnumpad.kicad_sch]
2025-09-02 RGBnumpad Footprint
    SMD 0805 hand solder footprints assigned to all of the parts on schematic
    [RGBnumpad.kicad_sch]
2025-09-02 ICANTDOTHISRGBPCB
    ICANTDOITICANTDOITICANTDOITICANTDOITICANTDOITICANTDOITICANTDOITICANTDOITICANTDOITICANTDOITICANTDOITICANTDOITICANTDOITICANTDOITICANTDOITICANTDOITICANTDOITICANTDOITICANTDOITICANTDOIT
    [RGBnumpad.kicad_pcb]
2025-09-03 rgb matrix and drc rules
    [T36K3BGR-05D000121U1930.step, numpad.kicad_pcb, numpad.kicad_sch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]
2025-09-03 fixed grid
    19.05 is grid size for pcb editor
    [numpad.kicad_pcb]
2025-09-04 ROT_SW
    Disconnect after S diode, ROT_SW
    [matrixrot.kicad_sch]
2025-09-04 LEDs attached to switches
    LEDs are assigned to the switches now
    [numpad.kicad_pcb]
2025-09-09 pcb stuff
    [matrixrot.kicad_sch, numpad.kicad_pcb, numpad.kicad_sch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]
2025-09-09 diodes placed except top 2 rows
    🐷
    [numpad.kicad_pcb]
2025-09-09 LEDs
    Placed all LEDs
    [numpad.kicad_pcb]
2025-09-10 pcb design draft
    [numpad.kicad_pcb, numpad.kicad_sch]
2025-09-11 bom list and some minor changes
    [numpad.csv, numpad.kicad_pcb]
2025-09-14 commit before merging to dev
    [numpad.kicad_pcb]
2025-09-16 really necessary silkscreen on pcb numpad
    [numpad.kicad_pcb_bom.csv, numpad.kicad_pcb_positions.csv]

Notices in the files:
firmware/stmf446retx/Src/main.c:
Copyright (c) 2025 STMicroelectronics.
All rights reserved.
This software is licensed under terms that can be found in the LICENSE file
